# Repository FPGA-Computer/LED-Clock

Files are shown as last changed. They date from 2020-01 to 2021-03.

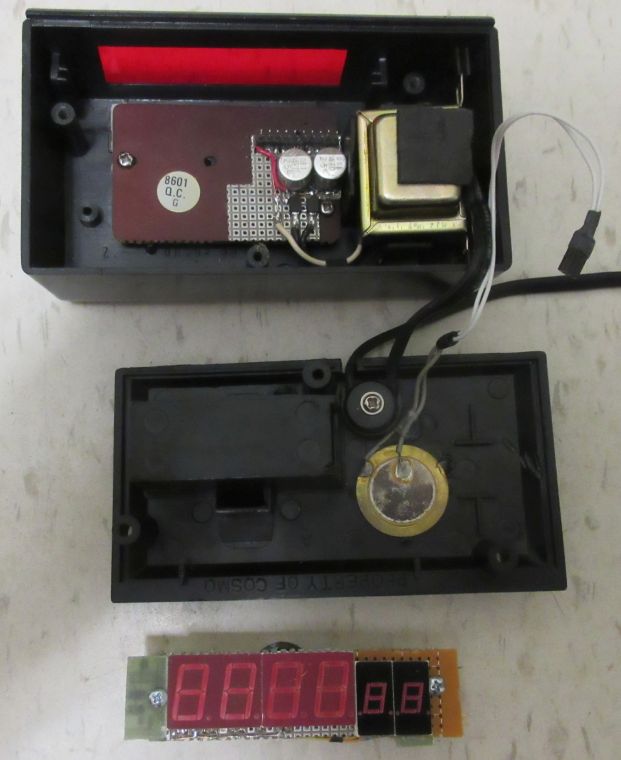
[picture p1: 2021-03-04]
Common anode/alarm clock PCB assemblies.jpg

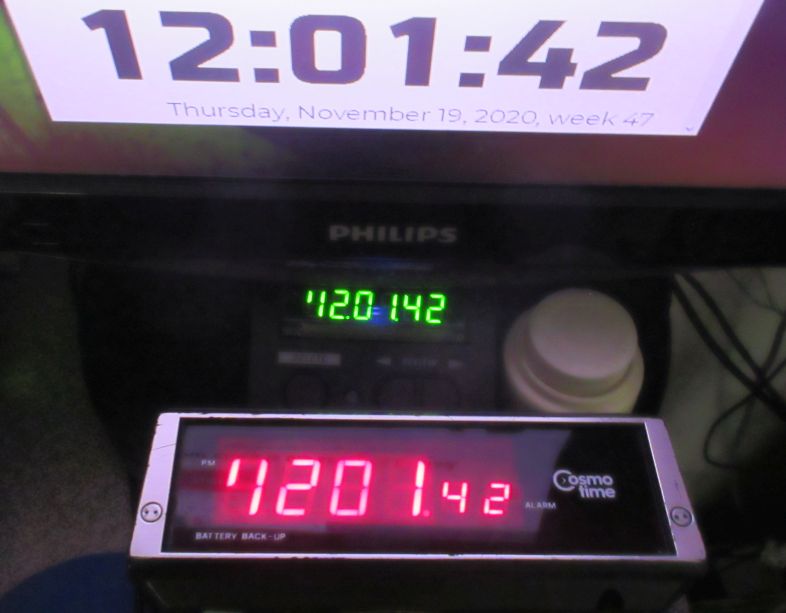
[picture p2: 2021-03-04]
digital clocks.jpg

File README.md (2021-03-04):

This is an accurate 6 digitals clock (HH.MM.SS) for the STM8S003.

Details: https://hw-by-design.blogspot.com/2019/11/stm8-led-clock-part-1.html

The RTC is implemented in firmware. It uses a 24-bit numerically-controlled 
oscillator (NCO) in formware for very fine accuracy adjustment.

Mine has been calibrated to within +/- 1 sec/month 
(room temperature is regulated by heaters.)

Common cathode/ 

efficient new 7 seg display with common cathode ~20mA

Common anode display/ 

old Alarm clock with recycled vintage large display from cable converter + 2 small displays. ~50mA
PNP anode drivers is needed.  Smaller display is more efficient, so I adjust their duty cycle in firmware.

Under those 2 directories:

Hardware/ - Eagle CAD schematic, PCB

Firmware/ - STM8S003 firmware source code

Firmware written by me are licensed under GPL 3.0.
It can be compiled using the free STM8 Cosmic C compiler.
Additional incorporated code are under their own licenses.

Hardware is licensed under CC BY-4.0

https://creativecommons.org/licenses/by/4.0/

History:

Initial release:
- bare minimal functionality, clock trim value is hard coded.

0.1 release
- added calendar

0.2 release
- added North America Daylight Saving Time (DST) + code clean up

0.3 release
- code cleanup
- added AC alarm clock using common anode display. Sorry messy wiring only, so no PCB

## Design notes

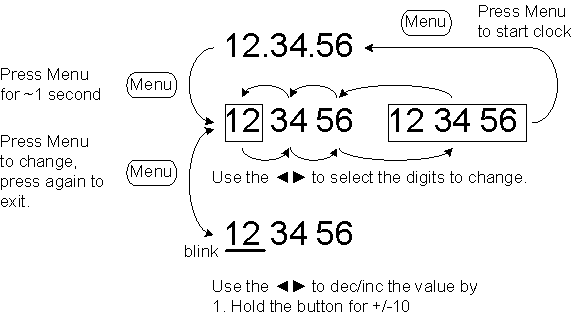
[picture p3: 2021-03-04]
set time.png

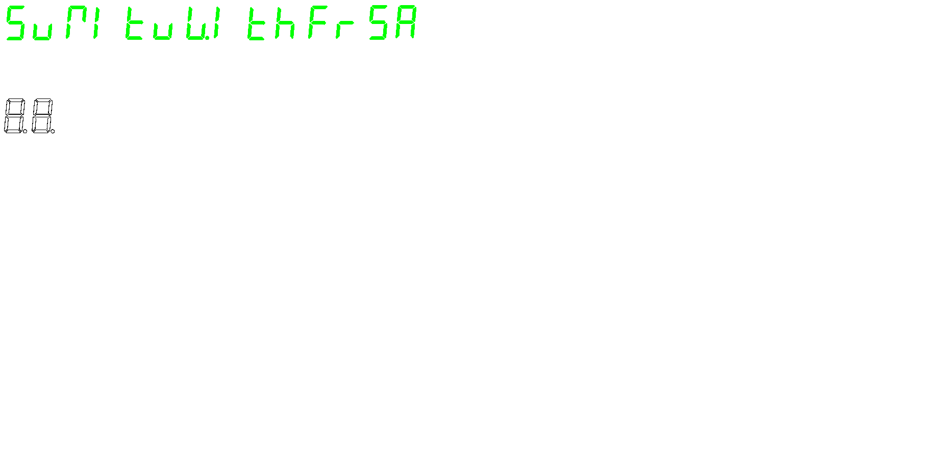
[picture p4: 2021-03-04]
day of week font.png

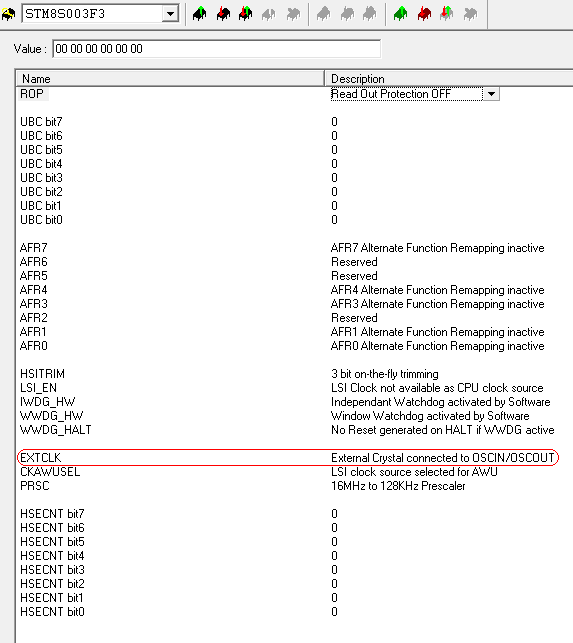
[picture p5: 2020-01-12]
fuse setting.png

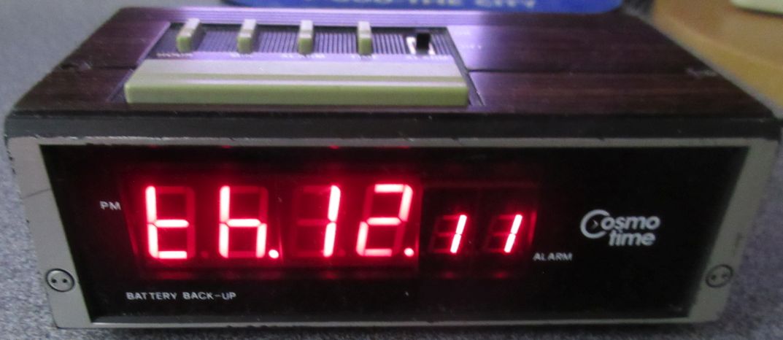
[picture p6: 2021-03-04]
Common anode/Calendar display.jpg

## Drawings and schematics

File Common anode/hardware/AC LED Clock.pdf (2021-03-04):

# MURS140 50R

A

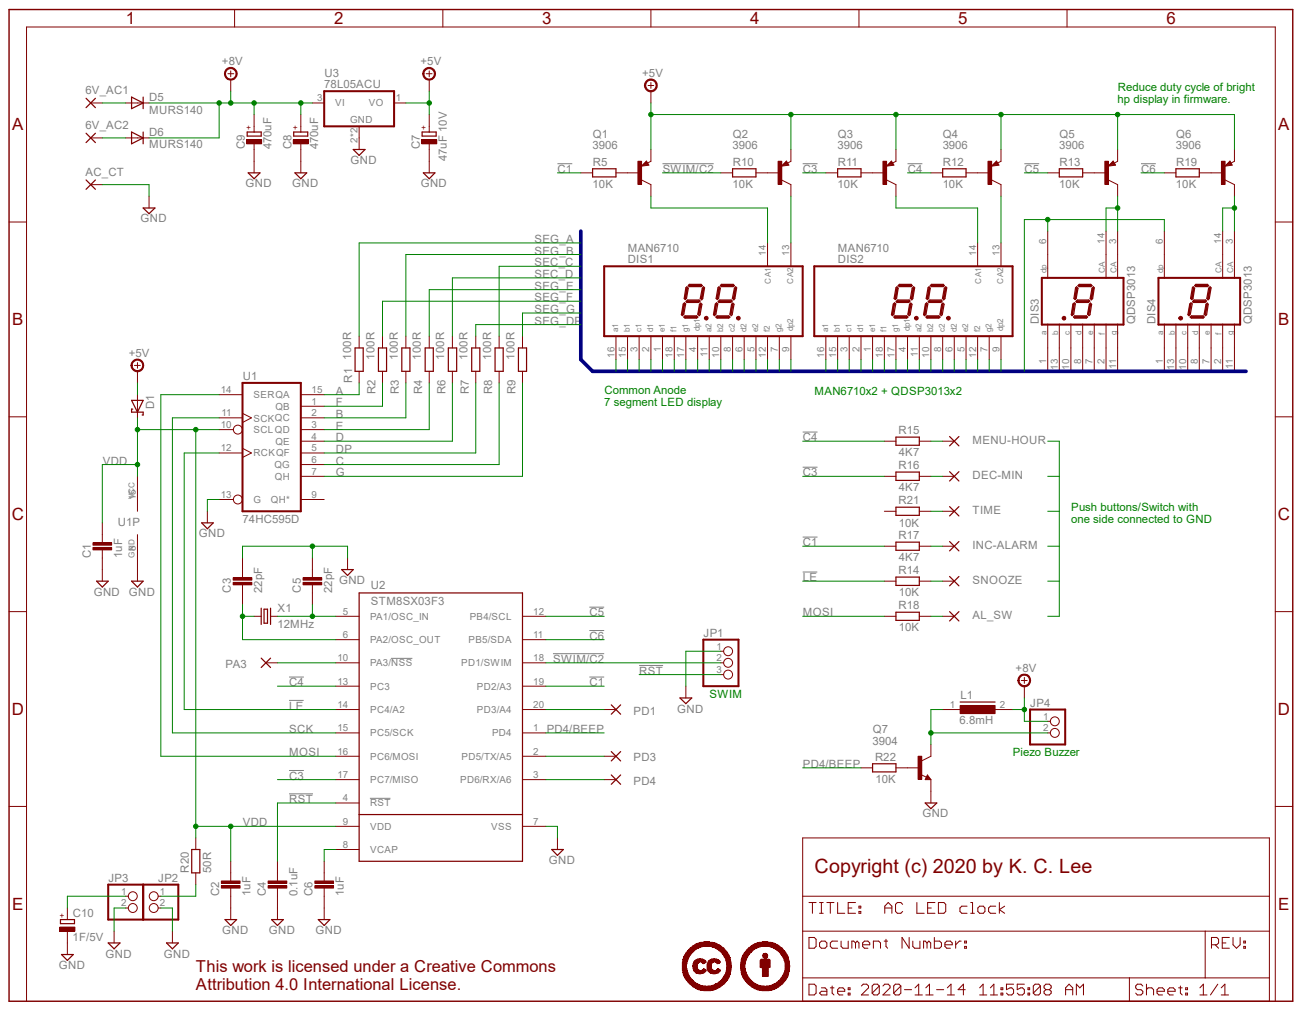
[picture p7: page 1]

Reduce duty cycle of bright
hp display in firmware.

SEG_E
SEG_F
SEG_G

Push buttons/Switch with
one side connected to GND

This work is licensed under a Creative Commons
Attribution 4.0 International License.

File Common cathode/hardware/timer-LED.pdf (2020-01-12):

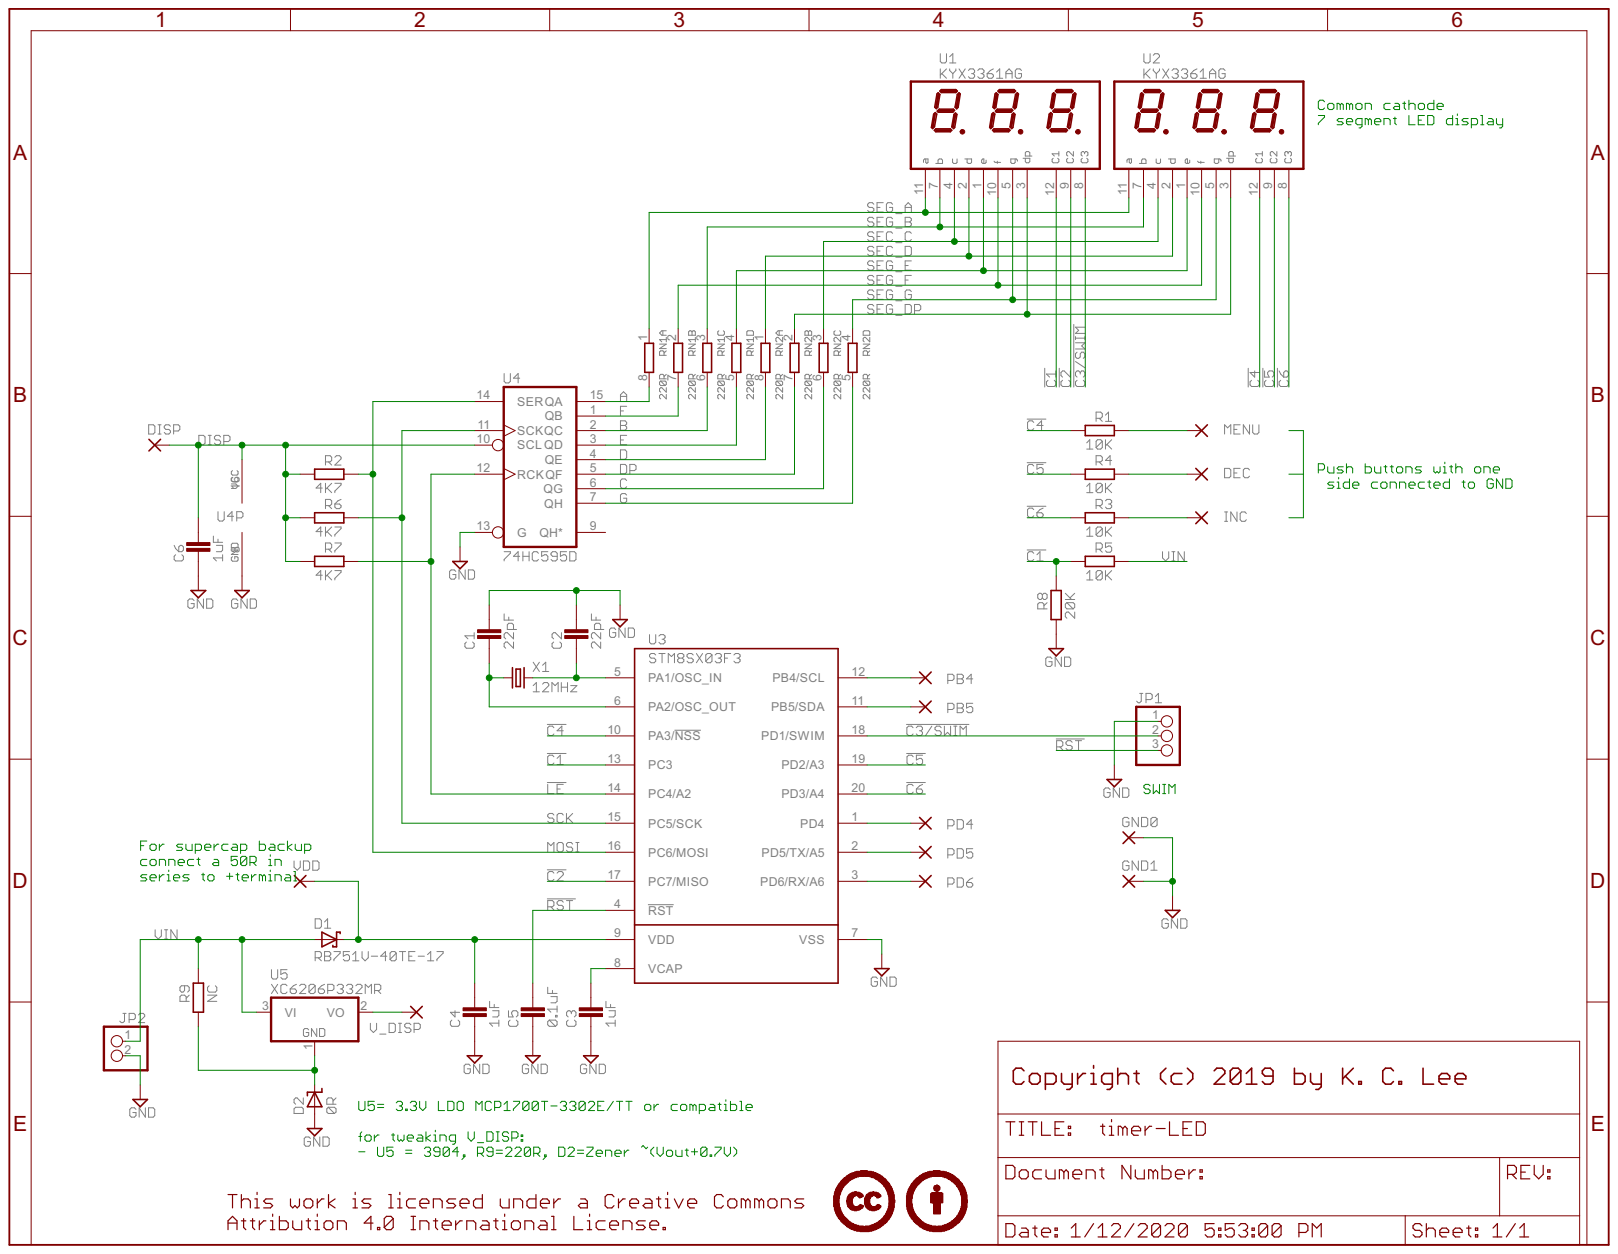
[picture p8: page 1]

3172011415912831720114159128 QB 1 QC 2 QD 3 QE 4 QF 5 QG 6 QH 7 SCL 10 SCK 11 RCK 12 G 13 SER 14 QA 15 QH* 9 PC6/MOSI 16 PC7/MISO 17 PC5/SCK 15 PA3/NSS 10 PB4/SCL 12 PB5/SDA 11 PC3 13 PC4/A2 14 PD3/A4 20 PD4 1 PD5/TX/A5 2 PD6/RX/A6 3 PD2/A3 19 VDD 9 VCAP 8 VSS 7 PD1/SWIM 18 RST 4 PA1/OSC_IN 5 PA2/OSC_OUT 6 8 16 1 8 2 7 3 6 4 5 1 8 2 7 3 6 4 5 123 12 VI 3 1 VO 2 ABCDE ABCDE 1 2 3 4 5 6

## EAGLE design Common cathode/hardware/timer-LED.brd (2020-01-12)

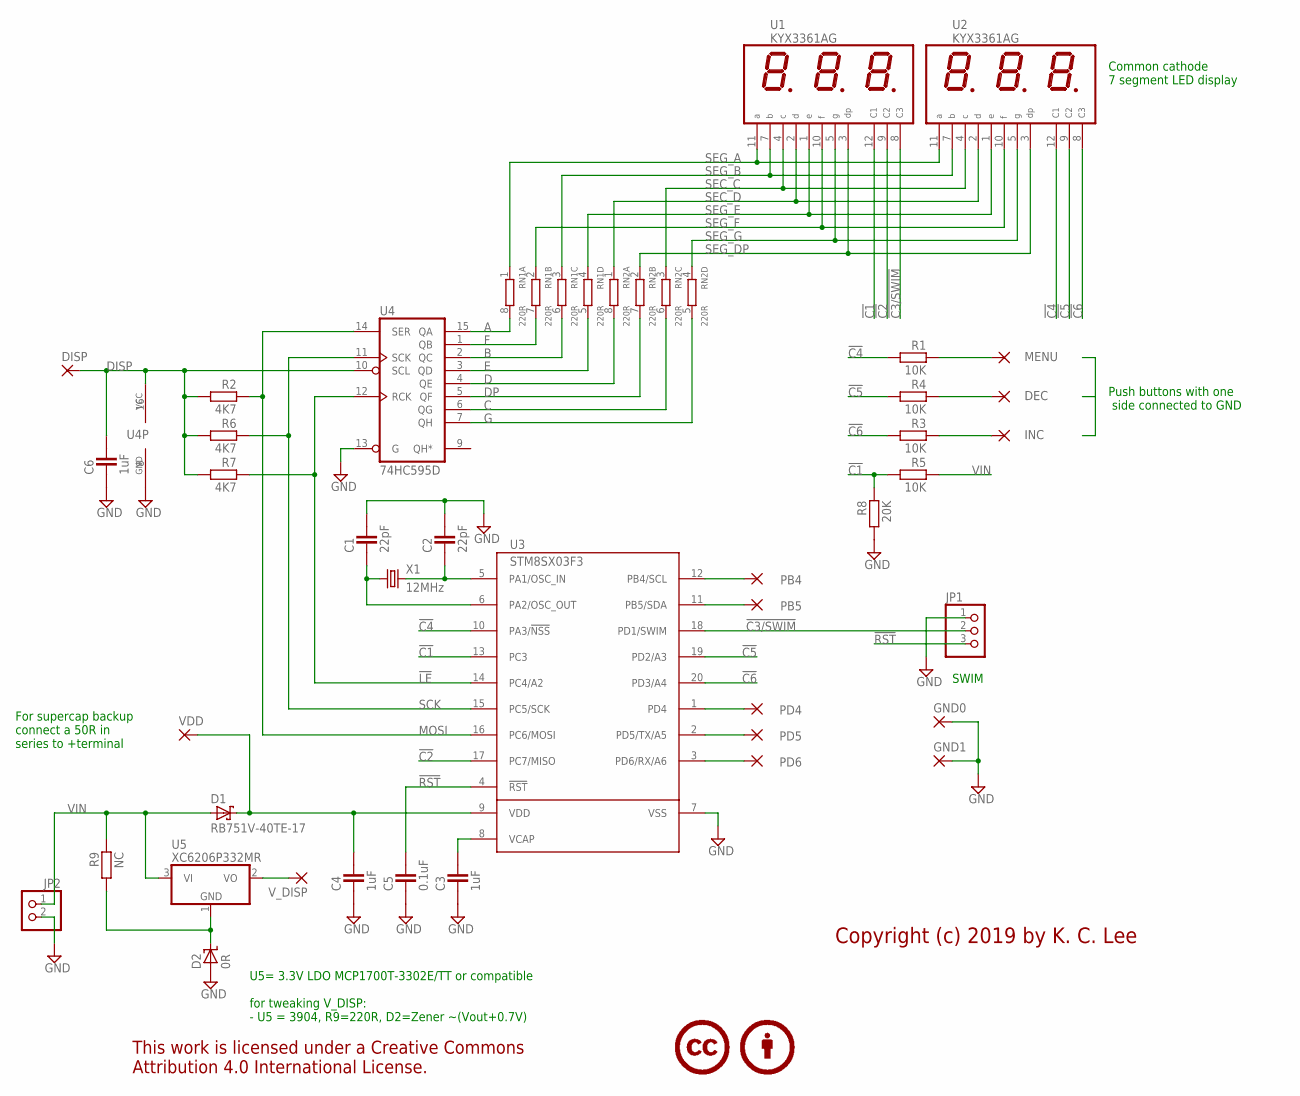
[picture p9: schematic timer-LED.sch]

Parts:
C1, C2: 22pF; CAPC1608X92N
C3, C4: 1uF; CAPC1608X92N
C5: 0.1uF; CAPC1608X92N
C6: 1uF; CAP2012X70N
D1: RB751V-40TE-17; SOD2514X100N
D2: 0R; SOD2514X100N
DEC: SMD2; SMD1,27-2,54
DISP: SMD2; SMD1,27-2,54
GND0, GND1: SMD2; SMD1,27-2,54
INC: SMD2; SMD1,27-2,54
JP1: PINHD-1X3; 1X03
JP2: PINHD-1X2_2.54; 1X02
LICENSE1: CC-BY75%; CC-BY-75
MENU: SMD2; SMD1,27-2,54
PB4, PB5: SMD2; SMD1,27-2,54
PD4, PD5, PD6: SMD2; SMD1,27-2,54
R1, R5: 10K; RESC1608X55N
R2, R6, R7: 4K7; RESC1608X55N
R3, R4: 10K; RESC2012X70N
R8: 20K; RESC1608X55N
R9: NC; RESC1608X55N
RN1, RN2: 220R; CAT16
U1, U2: KYX3361AG; KYX3361
U3: STM8SX03F3; TSSOP20
U4: 74HC595D; SO16
U5: XC6206P332MR; SOT95P280X135-3N
VDD: SMD2; SMD1,27-2,54
V_DISP: SMD2; SMD1,27-2,54
X1: 12MHz; HC49U-V

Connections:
!C1: R5.2, R8.1, U1.12 (C1), U3.13 (PC3)
!C2: U1.9 (C2), U3.17 (PC7/MISO)
!C3/SWIM: JP1.2, U1.8 (C3), U3.18 (PD1/SWIM)
!C4: R1.2, U2.12 (C1), U3.10 (PA3/!NSS)
!C5: R4.2, U2.9 (C2), U3.19 (PD2/A3)
!C6: R3.2, U2.8 (C3), U3.20 (PD3/A4)
!LE: R7.1, U3.14 (PC4/A2), U4.12 (RCK)
!RST: C5.2, JP1.3, U3.4 (!RST)
A: RN1.8 (2), U4.15 (QA)
B: RN1.6 (2), U4.2 (QC)
C: RN2.6 (2), U4.6 (QG)
D: RN2.8 (2), U4.4 (QE)
DISP: C6.2, DISP.1, R2.2, R6.2, R7.2, U4.10 (SCL), U4.16 (VCC)
DP: RN2.7 (2), U4.5 (QF)
E: RN1.5 (2), U4.3 (QD)
F: RN1.7 (2), U4.1 (QB)
G: RN2.5 (2), U4.7 (QH)
GND: C1.2, C2.2, C3.1, C4.1, C5.1, C6.1, D2.A, GND0.1, GND1.1, JP1.1, JP2.2, R8.2, U3.7 (VSS), U4.8 (GND), U4.13 (G)
MOSI: R2.1, U3.16 (PC6/MOSI), U4.14 (SER)
unnamed: DEC.1, R4.1
unnamed: PB4.1, U3.12 (PB4/SCL)
unnamed: PB5.1, U3.11 (PB5/SDA)
unnamed: PD5.1, U3.2 (PD5/TX/A5)
unnamed: PD6.1, U3.3 (PD6/RX/A6)
unnamed: PD4.1, U3.1 (PD4)
unnamed: INC.1, R3.1
unnamed: U5.2 (VO), V_DISP.1
unnamed: C1.1, U3.6 (PA2/OSC_OUT), X1.1
unnamed: D2.K, R9.2, U5.1 (GND)
unnamed: C2.1, U3.5 (PA1/OSC_IN), X1.2
unnamed: C3.2, U3.8 (VCAP)
unnamed: MENU.1, R1.1
SCK: R6.1, U3.15 (PC5/SCK), U4.11 (SCK)
SEC_C: RN2.3 (1), U1.4 (C), U2.4 (C)
SEC_D: RN2.1, U1.2 (D), U2.2 (D)
SEG_A: RN1.1, U1.11 (A), U2.11 (A)
SEG_B: RN1.3 (1), U1.7 (B), U2.7 (B)
SEG_DP: RN2.2 (1), U1.3 (DP), U2.3 (DP)
SEG_E: RN1.4 (1), U1.1 (E), U2.1 (E)
SEG_F: RN1.2 (1), U1.10 (F), U2.10 (F)
SEG_G: RN2.4 (1), U1.5 (G), U2.5 (G)
VDD: C4.2, D1.K, U3.9 (VDD), VDD.1
VIN: D1.A, JP2.1, R5.1, R9.1, U5.3 (VI)

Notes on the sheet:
SWIM
U5= 3.3V LDO MCP1700T-3302E/TT or compatible for tweaking V_DISP: - U5 = 3904, R9=220R, D2=Zener ~(Vout+0.7V)
Copyright (c) 2019 by K. C. Lee
Push buttons with one side connected to GND
For supercap backup connect a 50R in series to +terminal
Common cathode 7 segment LED display

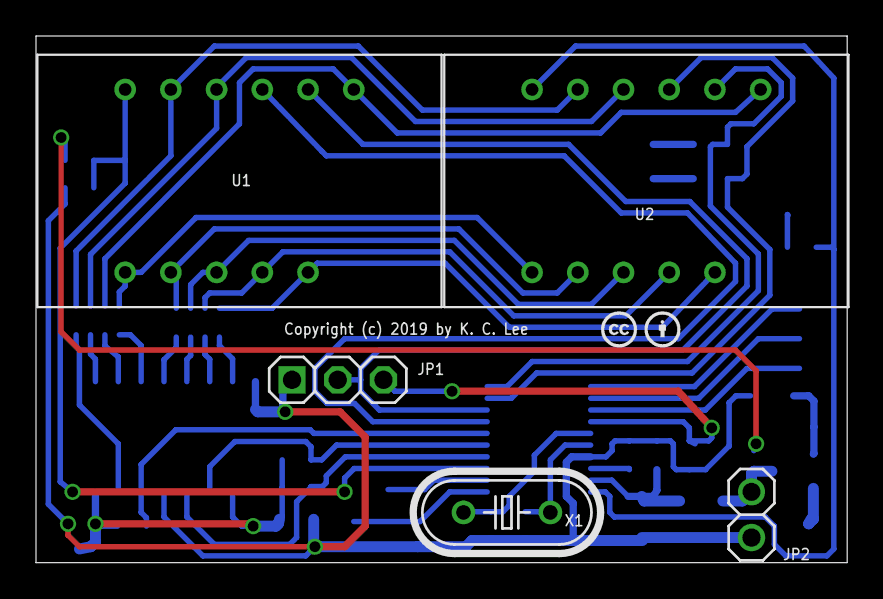
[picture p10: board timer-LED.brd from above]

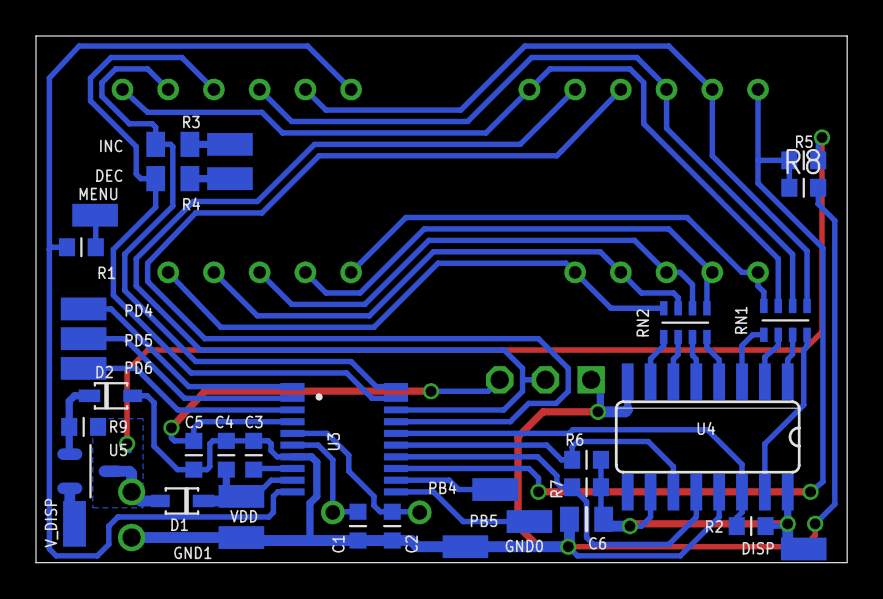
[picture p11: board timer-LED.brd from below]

Board: 2 copper layers, 45.1 x 29.3 mm, 41 parts (35 on the bottom side), 43 nets.

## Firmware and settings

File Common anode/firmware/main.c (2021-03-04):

/*
 * main.c
 *
 * Created: October 31, 2019, 12:33:01 PM
 *  Author: K. C. Lee
 * Copyright (c) 2019 by K. C. Lee
 
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
 If not, see http://www.gnu.org/licenses/gpl-3.0.en.html 
 */ 
 
#include "hardware.h"

void main(void)
{	
	// load Setting
	//	Load_Prefs(&Setting);
	
	time.DST_Enable = 1;
	
	Init_Hardware();

	while(1)
	{
		if(!debugger)
			wfi();				// save some extra power - doesn't work with debugger
		
		if(power)
		{
			if(time.Tick) 
			{
				time.Tick=0;
				ClockApp();
			}			
		}
		else
		  PowerDetect();
	}
}

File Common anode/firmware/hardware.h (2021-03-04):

/*
 * hardware.h
 *
 * Created: October 31, 2019, 12:33:01 PM
 *  Author: K. C. Lee
 * Copyright (c) 2019 by K. C. Lee
 
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
 If not, see http://www.gnu.org/licenses/gpl-3.0.en.html 
 */ 

#ifndef HARDWARE_H_
#define HARDWARE_H_

#ifndef __CSMC__
#define __CSMC__
#endif
#define STM8S003

#include "stm8s.h"
#include <stdio.h>

// STM8S003F3P6
enum _PA { PA1=0x02, PA2=0x04, PA3=0x08 };
enum _PB { PB4=0x10, PB5=0x20 };
enum _PC { PC3=0x08, PC4=0x10, PC5=0x20, PC6=0x40, PC7=0x80 };
enum _PD { PD1=0x02, PD2=0x04, PD3=0x08, PD4=0x10, PD5=0x20, PD6=0x40 };

enum _7SEG_ENCODE
{
	SEG_A=0x01,SEG_F=0x02,SEG_B=0x04,SEG_E=0x08,
	SEG_D=0x10,SEG_DP=0x20,SEG_C=0x40,SEG_G=0x80
};

#define AC_CLOCK
#define _7SEG_ACTIVE_LOW	1

enum _CA_DRV
{ 
	CC1=PD2,CC1_PORT=GPIOD_BaseAddress,
	CC2=PD1,CC2_PORT=GPIOD_BaseAddress,
	CC3=PC7,CC3_PORT=GPIOC_BaseAddress,
	CC4=PC3,CC4_PORT=GPIOC_BaseAddress,
	CC5=PB4,CC5_PORT=GPIOB_BaseAddress,
	CC6=PB5,CC6_PORT=GPIOB_BaseAddress
};

#define SPI_SCK					PC5
#define SPI_MOSI				PC6
#define SPI_LE					PC4

#define SPI_PINS				(SPI_SCK|SPI_MOSI|SPI_LE)
#define SPI_PORT				GPIOC
		
// PD2/AIN3 is also used for key input
#define ADC_KEY_CH			(3)
#define ADC_KEY_PIN			PD2

#define PB_COLS					(CC5|CC6)
#define PC_COLS					(CC3|CC4)
#define PD_COLS					(CC1)							// non-SWIM
#define PD_SWIM					PD1

#define KEY_PC					(CC3|CC4|SPI_MOSI|SPI_LE)
#define KEY_PD					(CC1)

#define KEY_PC_SHIFT		3

enum keys_encoding 	{ B_ALARM=0x04,B_TIME=0x00,B_MIN=0x10,B_HOUR=0x01,B_SNOOZE=0x08,KEY_SW=0x02,

											KEY_MENU=B_HOUR,KEY_DEC=B_MIN,KEY_INC=B_ALARM,KEY_ALARM_OFF = B_SNOOZE,
											KEY_MASK=0x1f,
											KEY_LONG=0x20, KEY_REPORTED=0x40, KEY_FLAG=0x80
										};

#define KEY_COL					1
#define SENSE_COL				1

// CPU divider = 1 -> 12MHz
//#define CPU_DIV					0

// CPU divider = 16 -> 750kHz
//#define CPU_DIV					0x04
// CPU divider = 4 -> 3MHz
#define CPU_DIV					0x02
// CPU divider = 128 -> 93.75kHz
#define CPU_SLOW				0x07

#define GPIO(X)					((GPIO_TypeDef *)(X))

#define SW_MENU					CC4
#define SW_INC					CC5
#define SW_DEC					CC6

#define UART_TX					PD5
#define UART_RX					PD6
#define UART_PORT				GPIOD

#define COLUMN_MAX			5

#define CPU_CLOCK				12000000UL
#define EE_Addr					0x4000

// 12MHz/128 -> 93750Hz
#define TIM4_PSCR				0x07
// 93750Hz/256 = 366Hz.  Full refresh = 366Hz/6 columns -> 61Hz
#define TIM4_ARR				0xff
// Dynamically adjusting duty cycle to eualize brighter smaller digits
#define TIM4_ARR_DIM		0x50
#define LED_DIM_COL			0x04
#define LED_NOM_COL			0x00

#define SCAN_PER_SEC		(CPU_CLOCK/(1<<TIM4_PSCR)/(1+TIM4_ARR)/(COLUMN_MAX+1))

#define BEEP_ON					(BEEP_CSR_BEEPEN|0x1e|0x40)
#define BEEP_OFF				BEEP_CSR_RESET_VALUE
#define BEEP_MASK				0x09

#define Beep_On()				BEEP->CSR =BEEP_ON
#define Beep_Off()			BEEP->CSR = BEEP_OFF

typedef struct 
{
	uint8_t		Bit;
	uint16_t	Port;
} Column_Drv_t;

#include "irq.h"
#include "time.h"
#include "key.h"
#include "ui.h"
#include "clock.h"
#include "menu.h"
//#include "eeprom.h"
//#include "serial.h"

extern const Column_Drv_t ColumnDrv[];

extern volatile uint8_t Display_Col,tick,update,power,debugger;
extern volatile uint8_t Display[];
extern const uint8_t CharMap[];

void Init_Hardware(void);
void Update(void);
uint8_t Key_Scan(void);
void PowerDetect(void);

#endif

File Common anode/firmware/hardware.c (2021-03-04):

/*
 * hardware.c
 *
 * Created: August 30, 2019, 6:35:08 PM
 *  Author: K. C. Lee
 * Copyright (c) 2016 by K. C. Lee
 
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
 If not, see http://www.gnu.org/licenses/gpl-3.0.en.html 
 */ 

#include "hardware.h"

volatile uint8_t Display_Col,tick,update,power,debugger;
volatile uint8_t Display[COLUMN_MAX+1];

const uint8_t CharMap[] =
{	
	Ch_0,Ch_1,Ch_2,Ch_3,Ch_4,Ch_5,Ch_6,Ch_7,
	Ch_8,Ch_9
	
#ifdef HEX_CHAR	
	,Ch_A,Ch_B,Ch_C,Ch_D,Ch_E,Ch_F
#endif	
};

const Column_Drv_t ColumnDrv[] = 
{	
	{	CC6,CC6_PORT },{ ~CC1,CC1_PORT }, 
	{	CC1,CC1_PORT },{ ~CC2,CC2_PORT },
	{	CC2,CC2_PORT },{ ~CC3,CC3_PORT },
	{ CC3,CC3_PORT },{ ~CC4,CC4_PORT },
	{	CC4,CC4_PORT },{ ~CC5,CC5_PORT },
	{	CC5,CC5_PORT },{ ~CC6,CC6_PORT },
};

Column_Drv_t *ColDrv;

void Init_Hardware(void)
{
	debugger = RST->SR & RST_SR_SWIMF;
	
	// Switch clock enable
	CLK->SWCR |= CLK_SWCR_SWEN;
	// Select HSE
	CLK->SWR = 0xb4;
	// wait for switching
	while(CLK->SWCR & CLK_SWCR_SWBSY)
	  /* */ ;
	
	CLK->CKDIVR = CPU_DIV;

	Display_Col =0;
	ColDrv = ColumnDrv;

	// column drivers = Push-pull, set to '1'
	GPIOB->DDR = GPIOB->CR1 = GPIOB->ODR = PB_COLS;
	GPIOC->DDR = GPIOC->CR1 = PC_COLS|SPI_PINS;
	GPIOC->ODR = PC_COLS|SPI_LE|SPI_MOSI;
	GPIOC->CR2 = SPI_PINS;												// SPI pins: Push-Pull/Fast I/O
	GPIOD->DDR = GPIOD->ODR = PD_COLS | PD_SWIM;
	// disable SWIM	push-pull
	GPIOD->CR1 = PD_COLS;

	// TIM4 - display update
	TIM4->PSCR = TIM4_PSCR;	
	TIM4->ARR = TIM4_ARR;	
	// TIM4 enable, ARR Preload
	TIM4->CR1 = TIM4_CR1_CEN|TIM4_CR1_ARPE;	
	TIM4->IER = TIM4_IER_UIE;	
	
	Time_Init();

	// SPI MSB first, Enable, Master, data rate = CPU/2
	SPI->CR1 = SPI_CR1_SPE|SPI_CR1_MSTR;
	// bidirection mode,output,software slave select,master
	SPI->CR2 = SPI_CR2_BDM|SPI_CR2_BDOE|SPI_CR2_SSM|SPI_CR2_SSI;

	power = 1;
	// Turn on interrupts
	rim();
}

// return raw key(s) pressed
	uint16_t ADC_Result;
	
uint8_t Key_Scan(void)
{
	uint8_t key, i, PortC, PortD;

	// Disable SPI 
	SPI->CR1 &= ~SPI_CR1_SPE;
	
	// set ports to input
	GPIOC->DDR &= ~KEY_PC;
	PortC = GPIOC->IDR;
	GPIOC->DDR |= KEY_PC;
	
	// Enable SPI
	SPI->CR1 |= SPI_CR1_SPE;
	
	GPIOD->DDR &= ~KEY_PD;
	PortD = GPIOD->IDR;
	GPIOD->DDR |= KEY_PD;

	key = ~(((PortC & KEY_PC)>>KEY_PC_SHIFT)|(PortD & KEY_PD))& KEY_MASK;
	return(key);
}

void PowerDetect(void)
{
	uint8_t detect;
	
	detect=(GPIOB->IDR & PB_COLS)!=0;

	if(power!=detect)		// detect a power change
	{
		if(detect)				// power returns
		{
			// enable timer 4
			TIM4->CR1 = TIM4_CR1_CEN;	
			CLK->CKDIVR = CPU_DIV;	
		}
		else							// power outage
		{
			// disable timer 4 - display refresh, key scan disabled
			TIM4->CR1 = 0;
			CLK->CKDIVR = CPU_SLOW;
			GPIOB->ODR = PB_COLS;
		}
		
		power = detect;
	}
}

// display update + scan keys
@far @interrupt void TIM4_Update_IRQ(void)
{
	TIM4->SR1 &= ~TIM4_SR1_UIF;
	
	// Turn off prev column	
	GPIO(ColDrv->Port)->ODR |= ColDrv++->Bit;
	
	if(_7SEG_ACTIVE_LOW)
		SPI->DR = ~Display[Display_Col];
	else
		SPI->DR = Display[Display_Col];

	// Move here as needed a delay to flush pipeline
	SPI_PORT->ODR &= ~SPI_LE;
	
	while(SPI->SR & SPI_SR_BSY)
		/* wait for transmit */;

	// latch SPI data
	SPI_PORT->ODR |= SPI_LE;
	
	// Turn on column
	GPIO(ColDrv->Port)->ODR &= ColDrv++->Bit;
	
	PowerDetect();
	
	switch(Display_Col++)
	{	
		case LED_NOM_COL:
			TIM4->ARR = TIM4_ARR;
			break;
	
		case LED_DIM_COL:
			TIM4->ARR = TIM4_ARR_DIM;
			break;
			
		case COLUMN_MAX:
			Key_Task();								// scan for keys
			Display_Col=0;
			ColDrv = ColumnDrv;
			break;
	}
}

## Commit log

2020-01-12 initial release
    [timer-LED.brd, timer-LED.sch]
2020-01-26 fixed day of week bug in RTC
    [time.c]
2020-11-01 fix daylight saving time
    [time.c]
2020-12-03 bug fixes and maintances
    [hardware.c, hardware.h, main.c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]
2021-03-04 Add AC alarm clock
    [timer-LED.brd, timer-LED.sch]
2021-03-09 fix DST start/end dates
    [UI.h, time.c]

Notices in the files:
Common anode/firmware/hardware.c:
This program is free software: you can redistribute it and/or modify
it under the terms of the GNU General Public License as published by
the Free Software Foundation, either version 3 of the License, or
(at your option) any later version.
